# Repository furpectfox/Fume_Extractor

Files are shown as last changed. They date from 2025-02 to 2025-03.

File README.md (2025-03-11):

# Fume Extractor
This Solder Fume Extractor features a 12V Noctua fan, with speed controlled by a PWM signal generated by a Colpitts sinusoidal oscillator circuit. The frequency generated is close to 25kHz, which is required by the Noctua fan. It also includes an LED strip to illuminate the workspace, with its brightness similarly controlled via PWM for greater efficiency. Since the supply voltage is 12V, using a linear regulator is inefficient and would create a lot of heat.

***Note***: Although this project could be greatly simplified by incorporating a microcontroller, like an ATtiny or ATmega, to generate the PWM signals for both the fan and LED strip, the aim here is to explore how to generate a square wave with a controllable duty cycle using entirely analog components.

## [Schematic](KiCad/Schematic.pdf)

## PCB
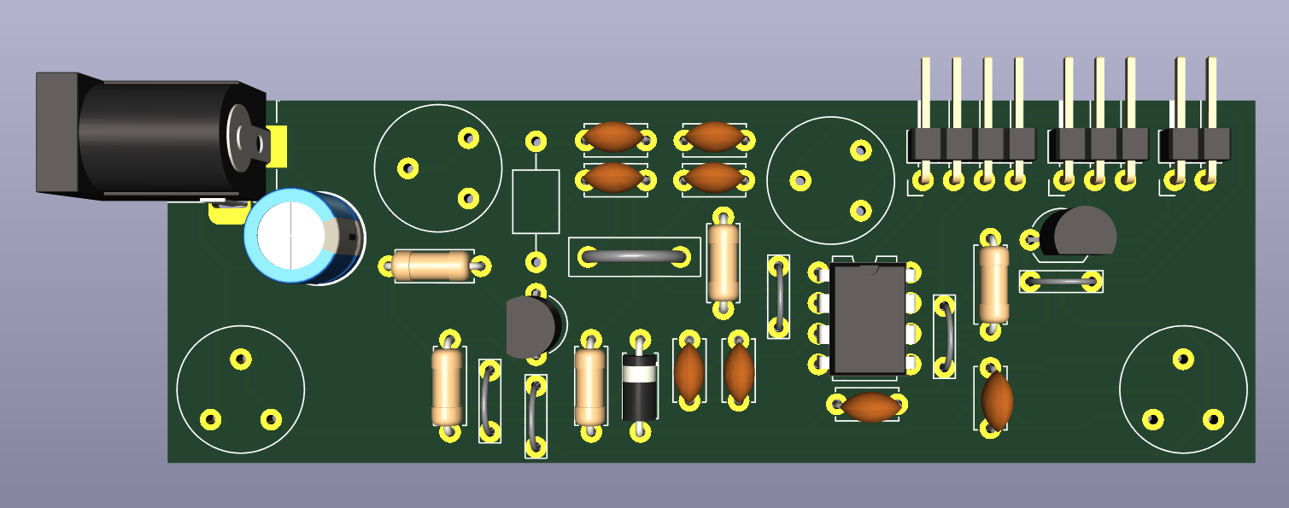
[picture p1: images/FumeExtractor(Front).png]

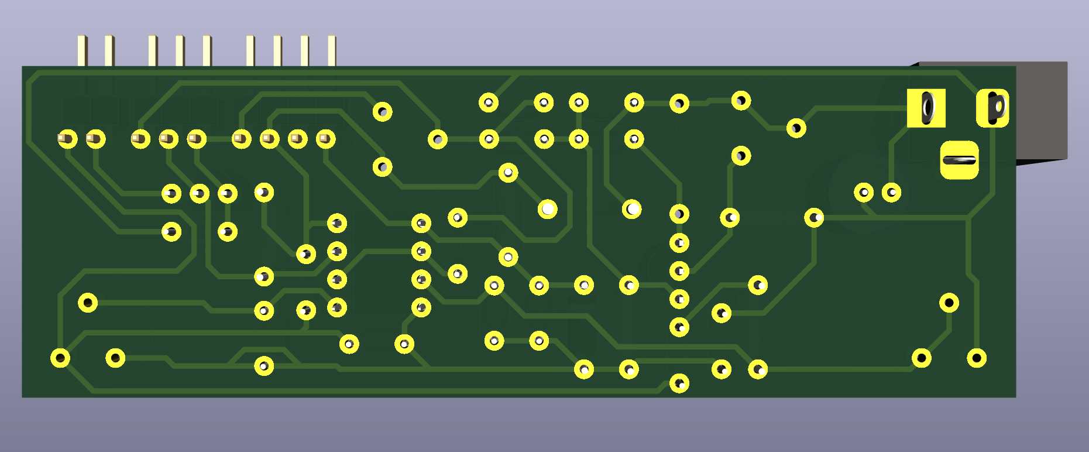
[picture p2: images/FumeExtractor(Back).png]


## 3D Model
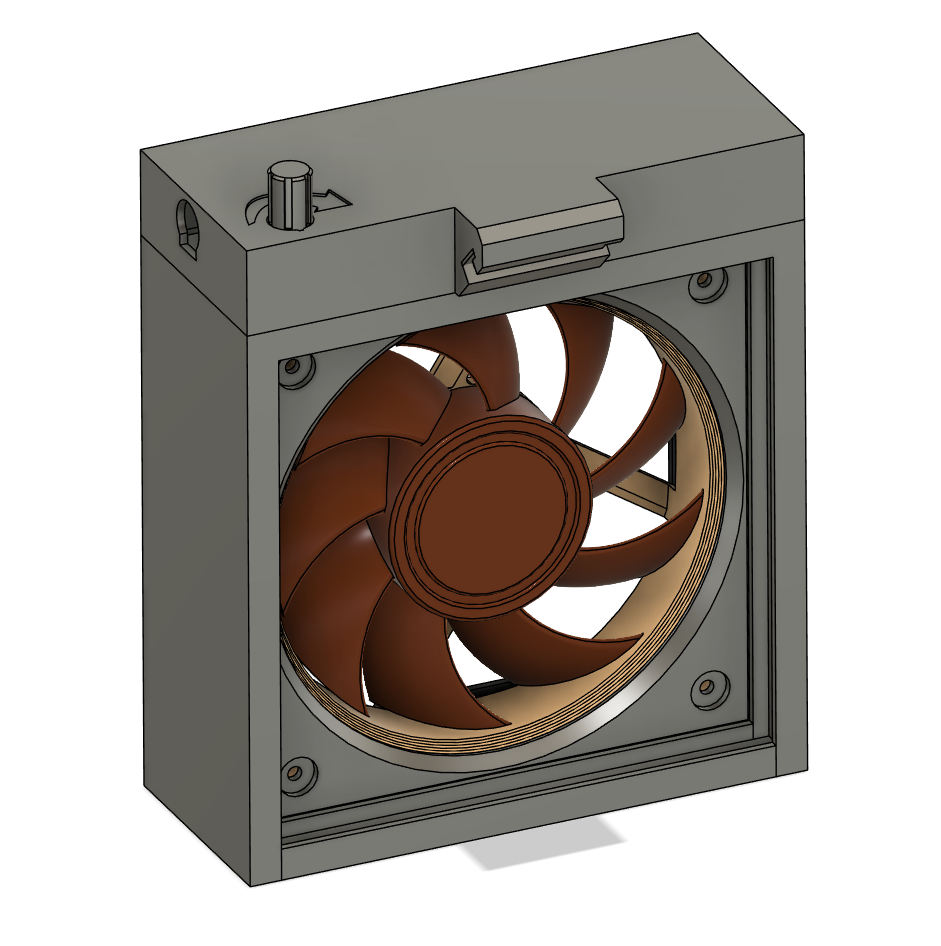
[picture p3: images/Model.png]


## Finish
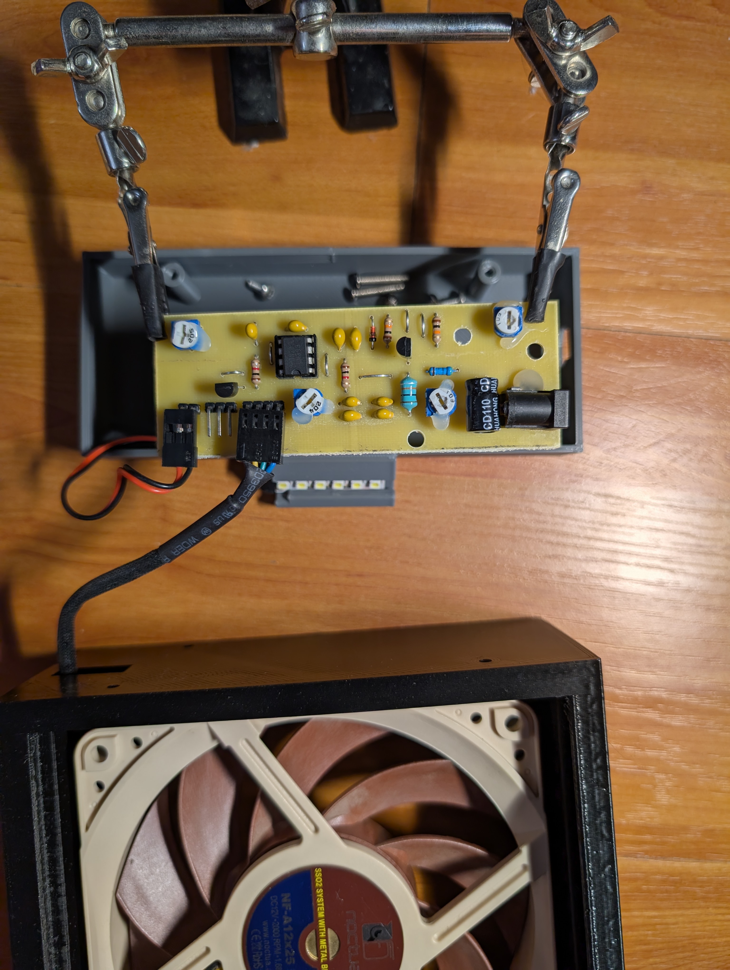
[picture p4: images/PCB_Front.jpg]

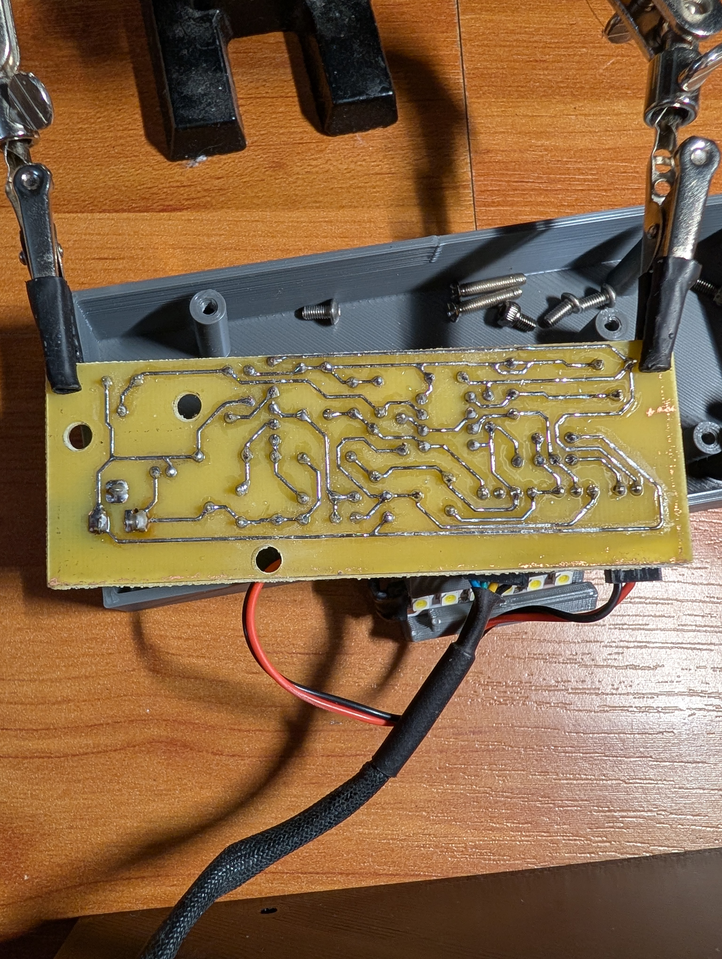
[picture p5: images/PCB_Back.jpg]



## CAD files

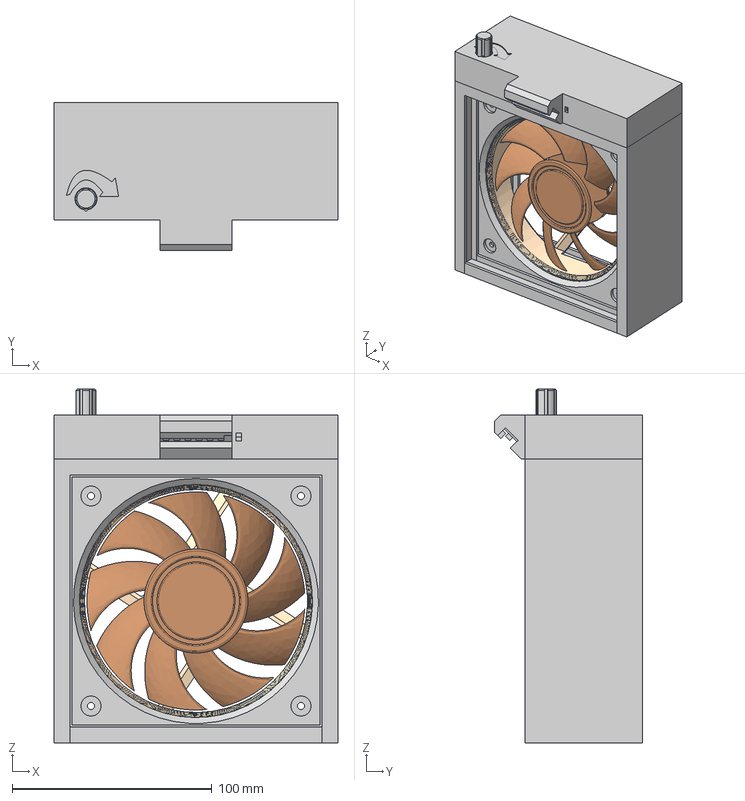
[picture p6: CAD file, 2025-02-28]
CAD/Fume_Extractor.step
142.0 x 73.8 x 177.0 mm
Frame
Fan
PCB

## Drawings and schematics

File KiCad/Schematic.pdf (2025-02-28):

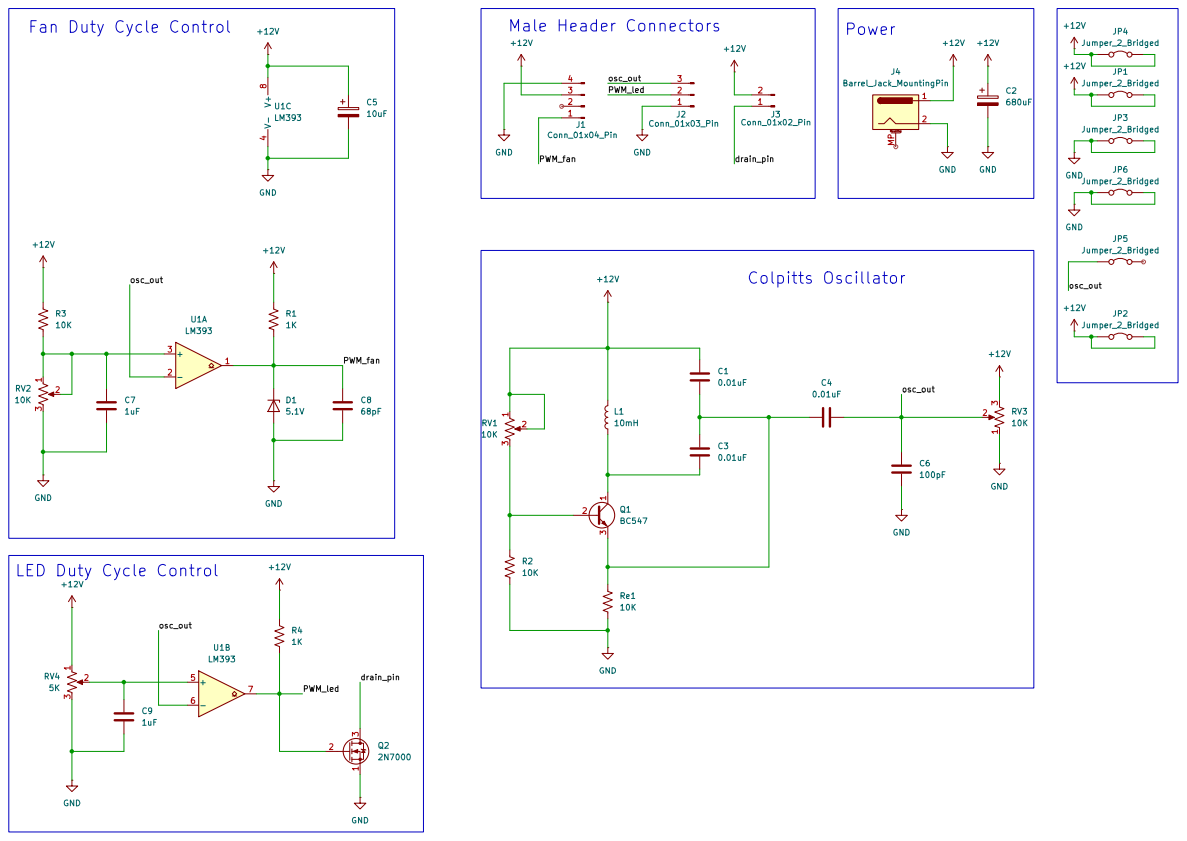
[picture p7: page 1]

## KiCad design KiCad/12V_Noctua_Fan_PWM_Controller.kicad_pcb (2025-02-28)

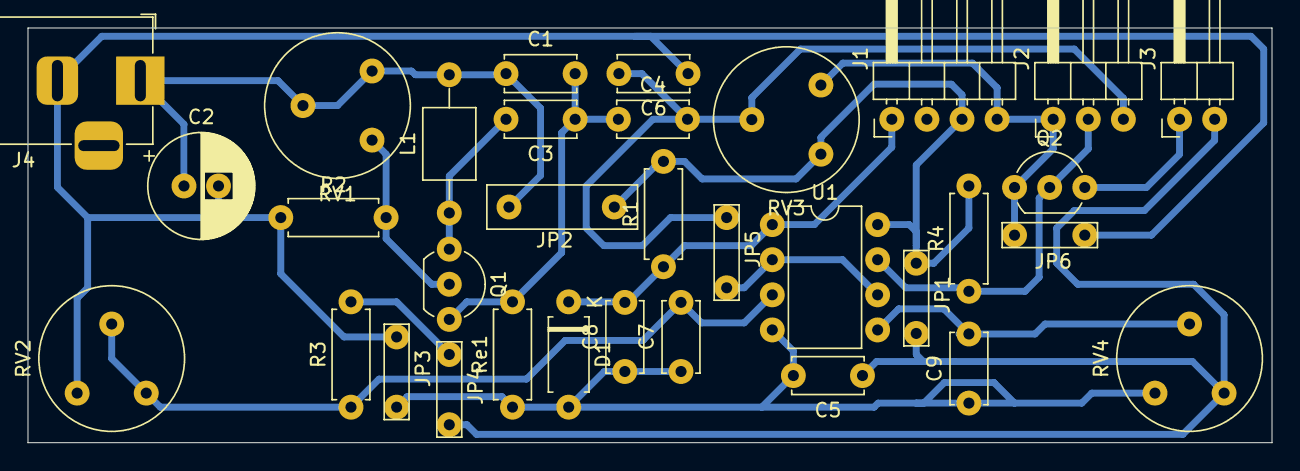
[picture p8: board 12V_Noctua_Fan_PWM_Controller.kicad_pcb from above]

Board: 2 copper layers, 90.0 x 30.0 mm, 33 parts (0 on the bottom side), 11 nets.

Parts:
C1, C3, C4: 0.01uF; C_Disc_D5.0mm_W2.5mm_P5.00mm
C2: 680uF; CP_Radial_D7.5mm_P2.50mm
C5: 10uF; C_Disc_D5.0mm_W2.5mm_P5.00mm
C6: 100pF; C_Disc_D5.0mm_W2.5mm_P5.00mm
C7, C9: 1uF; C_Disc_D5.0mm_W2.5mm_P5.00mm
C8: 68pF; C_Disc_D5.0mm_W2.5mm_P5.00mm
D1: 5.1V; D_A-405_P7.62mm_Horizontal
J1: Conn_01x04_Pin; PinHeader_1x04_P2.54mm_Horizontal
J2: Conn_01x03_Pin; PinHeader_1x03_P2.54mm_Horizontal
J3: Conn_01x02_Pin; PinHeader_1x02_P2.54mm_Horizontal
J4: Barrel_Jack_MountingPin; BarrelJack_Horizontal
JP1, JP3, JP4, JP5, JP6: Jumper_2_Bridged; TestPoint_Bridge_Pitch5.08mm_Drill0.7mm
JP2: Jumper_2_Bridged; TestPoint_Bridge_Pitch7.62mm_Drill1.3mm
L1: 10mH; L_Axial_L5.0mm_D3.6mm_P10.00mm_Horizontal_Murata_BL01RN1A2A2
Q1: BC547; TO-92_Inline_Wide
Q2: 2N7000; TO-92_Inline_Wide
R1, R4: 1K; R_Axial_DIN0207_L6.3mm_D2.5mm_P7.62mm_Horizontal
R2, R3: 10K; R_Axial_DIN0207_L6.3mm_D2.5mm_P7.62mm_Horizontal
RV1, RV2, RV3: 10K; Potentiometer_Piher_PT-10-V05_Vertical
RV4: 5K; Potentiometer_Piher_PT-10-V05_Vertical
Re1: 10K; R_Axial_DIN0207_L6.3mm_D2.5mm_P7.62mm_Horizontal
U1: LM393; DIP-8_W7.62mm

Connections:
+12V: C1.1, C2.1, C5.1, J1.3, J3.2, J4.1, JP1.1 (A), JP2.1 (A), JP4.1 (A), L1.2, R1.2, R3.2, R4.2, RV1.1, RV1.2, RV3.3, RV4.1, U1.8 (V+)
/PWM_fan: C8.2, D1.1 (K), J1.1, R1.1, U1.1
/PWM_led: J2.2, Q2.2 (G), R4.1, U1.7
/drain_pin: J3.1, Q2.3 (D)
/osc_out: C4.2, C6.2, J2.3, JP5.1 (A), RV3.2, U1.2 (-), U1.6 (-)
GND: C2.2, C5.2, C6.1, C7.1, C8.1, C9.1, D1.2 (A), J1.4, J2.1, J4.2, JP3.1 (A), JP6.1 (A), Q2.1 (S), R2.1, RV2.3, RV3.1, RV4.3, Re1.1, U1.4 (V-)
unnamed: Q1.2 (B), R2.2, RV1.3
unnamed: C3.2, L1.1, Q1.1 (C)
unnamed: C1.2, C3.1, C4.1, Q1.3 (E), Re1.2
unnamed: C7.2, R3.1, RV2.1, RV2.2, U1.3 (+)
unnamed: C9.2, RV4.2, U1.5 (+)

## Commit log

2025-02-28 first comit
    [12V_Noctua_Fan_PWM_Controller.kicad_pcb, 12V_Noctua_Fan_PWM_Controller.kicad_sch]
2025-02-28 add CAD Model of Fume Extractor
    [Fume_Extractor.step]
2025-03-11 Organize files
    [Fume_Extractor.step]
